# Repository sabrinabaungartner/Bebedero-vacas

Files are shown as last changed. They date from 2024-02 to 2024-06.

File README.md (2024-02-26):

# Bebedero-vacas
El objetivo de este repositorio es almacenar el proyecto, como así también documentos relacionados al proyecto final de carrera Ingeniería en Computación.

## Objetivos
* Asociar dos esp32 con dos LoRa
  * esp32 con un LoRa hacen de transmisores, y el otro LoRa con el esp32 hacen de receptores.
* Sensor de temperatura en el bebedero --> para indicar cuando resulta necesario cambiar el agua.
* Sensor de nivel del agua --> para indicar cuándo se debe rellenar el mismo.
* Sensor de ph --> determina si el agua estancada comienza degradar su calidad.
* Conteo de la cantidad de días sin llenar el bebedero --> determina si el agua estancada comienza degradar su calidad.
* Tomar métricas de cantidad de agua consumida en un día (fecha y consumición).
  * Tipo de vaca: lechera, para carne. Consumirán más o menos líquido. Dependiendo del tipo de vaca, si el ganado es de carne consume 3 litros por día y por cada kilogramo de materia seca consumida, con una temperatura media anual de 5°C. Para un ganado de leche, una vaca lechera consume de 3 a 4 litros de agua por cada kilogramo de leche producida y de 3 a 4 litros de agua por cada kilogramo de materia seca consumida en su dieta.
* App para dueño del campo
  * La app estará tomando valores desde Firebase y decidirá si es necesario enviar una notificación al usuario para informarle sobre algún cambio relevante:
    * Agua en mal estado.
    * Filtrado del agua.
    * Temperatura del agua por arriba o debajo de un cierto umbral.
    * Nivel bajo de agua.
* Hay un LoRa que se va a encontrar en los bebederos. Este dispositivo debe recibir los censados cada cierta cantidad de tiempo y enviárselos al otro LoRa, el cual tomará esos valores y los guardará en la db.

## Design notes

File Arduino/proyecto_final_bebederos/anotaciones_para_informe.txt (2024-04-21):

libreria usada ESP32 Firebase by Rupak Poddar
https://www.arduino.cc/reference/en/libraries/esp32-firebase/
documentacion 
https://github.com/Rupakpoddar/ESP32Firebase/tree/main

// ************************************************** //
ENTRADAS RESERVADAS DEL ESP32 PARA WIFI
Solo se puede usar los puertos del ADC2 cuando el no se usa el wifi. Pines:
* D25
* D26
* D27
* D14
* D12
* D13
* D15
* D2
* D4

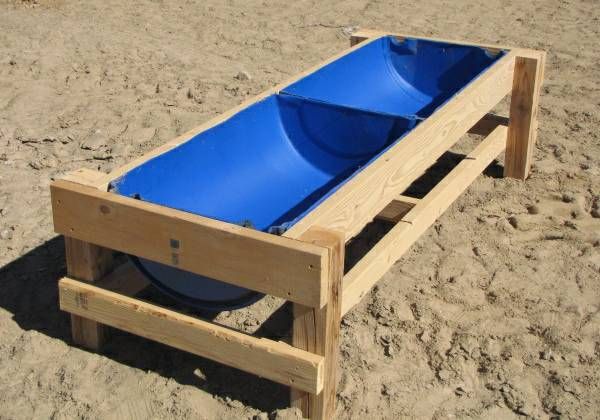
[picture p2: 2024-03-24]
Diseños/Arduino/d69348b3ec312043967b3d7c50ac29f3.jpg

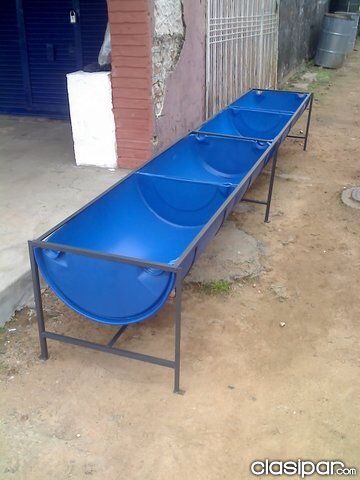
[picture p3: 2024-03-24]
Diseños/Arduino/fdcc297894d32a51d415da545de93732.jpg

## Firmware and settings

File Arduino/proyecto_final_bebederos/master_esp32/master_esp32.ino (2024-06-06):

#include <Arduino.h>
#include "firebase_handler.h"
#include "bt_handler.h"
#include "fnqueue.h"
#include "timer.h"

#define GET_WATER_LEVEL_AND_TEMPERATURE 1
#define REPLY_WATER_LEVEL_AND_TEMPERATURE 2
#define TURN_ON_PUMP 3
#define TURN_OFF_PUMP 4
#define REPLY_TURN_ON_PUMP 5
#define REPLY_TURN_OFF_PUMP 6
#define GET_WATER_LEVEL 7
#define REPLY_WATER_LEVEL 8
#define NULO 0
#define MAX_SECONDS_PUMP_ON 50

// Variables
int seconds = 0;
int seconds_filling_waterer = 0;
int water_level = 0;
int cattle_waterer_selected = 1;
int days_without_fill_waterer = 0;
int filling_waterer = 0;
float water_temperature = 0.0;
bool wifi_is_connected = false;
int max_water_level = 0;
int turn_off_water_pump = 0;
int fill_waterer = 0;
int seconds_pump_on = 0;

// Declaration of functions
void iniciar_timer();
void funcion_timer();
void update_status_cattle_waterer();
void request_and_receive_water_level_and_temperature();
void reset_values_after_filling_waterer();

void request_and_receive_water_level_and_temperature() {
  request_to_slave(GET_WATER_LEVEL_AND_TEMPERATURE);
  receive_from_slave();
  if (get_message_received() == REPLY_WATER_LEVEL_AND_TEMPERATURE) {
    water_level = receive_requested_water_level();
    water_temperature = receive_requested_water_temperature();
    Serial.print("water level value: ");
    Serial.println(water_level);
    Serial.print("water level temperature: ");
    Serial.println(water_temperature);
  }
  else {
    Serial.println("no recibi del slave");
    water_level = 0;
    water_temperature = 0.0;
  }
}

void reset_values_after_filling_waterer() {
  set_fill_waterer(0, cattle_waterer_selected);
  set_last_filling_date(cattle_waterer_selected);
  set_days_without_filling(0, cattle_waterer_selected);
  reset_last_check_filling_date(cattle_waterer_selected);
  set_is_water_pump_enabled(0, cattle_waterer_selected); // Android app detects this change and use it to enable "rellenar bebedero" button
}

void update_status_cattle_waterer() {
  set_current_water_level_value(water_level, cattle_waterer_selected);
  set_current_water_temperature_value(water_temperature, cattle_waterer_selected);
  set_current_date(cattle_waterer_selected);
  update_days_without_filling(cattle_waterer_selected);
}

void funcion_timer() {
  if (!check_slave_is_connected()) {
    Serial.println("Serial BT communicaton is not seted!");
    connect_to_slave();
    seconds = 0;
  }

  else {
    if (seconds == 2) {
      fill_waterer = get_fill_waterer(cattle_waterer_selected);
      if ((fill_waterer == 1) && (filling_waterer == 0)) { // Check if it is necessary to refill the waterer and if it is not filling
          request_to_slave(TURN_ON_PUMP);
          receive_from_slave();
          if (get_message_received() == REPLY_TURN_ON_PUMP) {
            set_is_water_pump_enabled(1, cattle_waterer_selected); // Enable water pump in Firebase
            filling_waterer = 1;
            seconds_pump_on = 0;
            Serial.println("requeri prender la bomba al slave y el slave me respondio que la prendio");
          }
      }
    }

    if (seconds == 4) {
      if ((fill_waterer == 1) && (filling_waterer == 1) && !turn_off_water_pump) { // Check if it is necessary to fill waterer, if it is filling waterer and if not must to turn of the pump
        request_to_slave(GET_WATER_LEVEL);
        receive_from_slave();
        Serial.println("pedi y recibi nivel del agua");
        if ((receive_requested_water_level() >= max_water_level) || (seconds_pump_on >= MAX_SECONDS_PUMP_ON)) {
          turn_off_water_pump = 1;
          Serial.println("la bomab se tiene que apagar!");
          Serial.print("seconds_pump_on: ");
          Serial.println(seconds_pump_on);
        }
      }
    }

    if (seconds == 6) {
      if (fill_waterer == 1) { // Check if it is necessary to fill waterer and if the waterer is filling
        if (filling_waterer == 1) {
          if (turn_off_water_pump) {
            Serial.println("voy a pedir que se apague la bomba");
            request_to_slave(TURN_OFF_PUMP);
            Serial.println("ya mande que se apague la bomba");
            receive_from_slave();
            Serial.println("Pedi que se apague la bomba, voy a ver qye recbo");
            if (get_message_received() == REPLY_TURN_OFF_PUMP) {
              Serial.println("me respondieron que se apago la bomba");
              reset_values_after_filling_waterer();
              filling_waterer = 0;
              turn_off_water_pump = 0;
              fill_waterer = 0;
              seconds_pump_on = 0;
            }
          }
        }
        seconds = 0;
      }
    }

    if (seconds == 8) {
      request_and_receive_water_level_and_temperature();
    }

    if (seconds == 10) {
      update_status_cattle_waterer();
    }

    if (seconds == 12) {
      backup_current_data(cattle_waterer_selected);
      seconds = 0;
    }

    if (filling_waterer == 1) { // Incrementar el contador de tiempo solo si la bomba está encendida
      seconds_pump_on += 1;
    }
  }

  seconds += 1;
}

void iniciar_timer(){
  timer_init(&funcion_timer, 1000000);
  timer_start();
}

void setup() {
  Serial.begin(115200);
  setup_wifi_firebase();
  set_NTP_server();
  setup_bluetooth_configuration();
  fnqueue_init();
  iniciar_timer();
  set_last_filling_date(cattle_waterer_selected);
  reset_last_check_filling_date(cattle_waterer_selected);
  set_days_without_filling(0, cattle_waterer_selected);
  max_water_level = get_max_water_level(cattle_waterer_selected);
  Serial.print("max water level: ");
  Serial.println(max_water_level);
}

void loop() {
  fnqueue_run();
}

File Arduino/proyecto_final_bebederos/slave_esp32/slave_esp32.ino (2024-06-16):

#include <Arduino.h>
#include "slave_serial_bt.h"
#include "water_level_sensor.h"
#include "water_sensor_temperature.h"
#include "fnqueue.h"
#include "timer.h"
#include "water_pump.h"

#define GET_WATER_LEVEL_AND_TEMPERATURE 1
#define REPLY_WATER_LEVEL_AND_TEMPERATURE 2
#define TURN_ON_PUMP 3
#define TURN_OFF_PUMP 4
#define REPLY_TURN_ON_PUMP 5
#define REPLY_TURN_OFF_PUMP 6
#define GET_WATER_LEVEL 7
#define REPLY_WATER_LEVEL 8
#define NULO 0
#define LED_MICRO_ON 22

// Variables
uint8_t seconds = 0;
uint8_t request_received = 0;
uint8_t request = 0;
int water_level = 0;
float water_temperature = 0.0;

void iniciar_timer();
void funcion_timer();
void check_request();
void determine_request();
void response_request();
void read_water_temperatura_from_sensor();
void read_water_level_from_sensor();

void setup() {
  Serial.begin(115200);
  pinMode(LED_MICRO_ON, OUTPUT);
  digitalWrite(LED_MICRO_ON, HIGH);
  setup_bluetooth_configuration();
  setup_water_level_sensor();
  setup_water_temperature_sensor();
  setup_water_pump();
  fnqueue_init();
  iniciar_timer();
}

void loop() {
  fnqueue_run();
}

void iniciar_timer(){
  timer_init(&funcion_timer, 1000000);
  timer_start();
}

void funcion_timer() {
  if (seconds == 1) {
    check_request();
  }

  if (seconds == 2) {
    if (request_received) {
      Serial.println("recibi algo!");
      determine_request();
    }
  }

  if (seconds == 3) {
    if (request_received) {
      response_request();
    }
    seconds = 0;
  }

  seconds += 1;
}

void check_request() {
  request_received = bluetooth_SPP_RxHandler();
}

void determine_request() {
  request = get_message_type_of_request();

  switch(request) {
    case GET_WATER_LEVEL_AND_TEMPERATURE:
      Serial.println("Me pidieron nivel y temperatura");
      read_water_level_from_sensor();
      read_water_temperature_from_sensor();
      break;
    case GET_WATER_LEVEL:
      Serial.println("Me pidieron nivel del agua");
      read_water_level_from_sensor();
      break;
    case TURN_ON_PUMP:
      Serial.println("Me pidieron prender la bomba");
      turn_on_water_pump();
      break;
    case TURN_OFF_PUMP:
      turn_off_water_pump();
      break;
  }
}

void read_water_level_from_sensor() {
  water_level = get_water_level();
}

void read_water_temperature_from_sensor() {
  water_temperature = get_water_temperature();
}

void response_request() {
  switch(request) {
    case GET_WATER_LEVEL_AND_TEMPERATURE:
      Serial.println("Voy a enviar nivel y temperatura");
      bluetooth_SPP_TxHandler(water_level, water_temperature);
      break;
    case GET_WATER_LEVEL:
      bluetooth_SPP_TxHandler(water_level, NULO);
      break;
    case TURN_ON_PUMP:
      bluetooth_SPP_TxHandler(NULO, NULO);
      break;
    case TURN_OFF_PUMP:
      bluetooth_SPP_TxHandler(NULO, NULO);
      break;
  }
}

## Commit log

2024-02-27 Diseño preliminar de la app hecho con Figma
    Link donde se encuentra el diseño: https://www.figma.com/file/cv35BSG2QaFzLYQss9WWen/Untitled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
2024-03-04 se agrego en la interfaz un circulo de barra que muestra un promedio (proximamente) y se empezo a realizar la comunicacion con firebase
2024-03-06 se agrego una manera de que visualmente se vean los cambios realizados desde firebase
2024-03-06 factorizacion y mejora visual de los elementos para mostrar la temperatura promedio, promedio y temperatura maxima
2024-03-08 se acomodo el progressbar para el nivel del agua
2024-03-08 se agrego texto al progress bar del nivel de agua
2024-03-08 se agregaron los tres progressBar de los tres parametros a tener en cuenta
2024-03-10 se agregaron iconos de carga de pantalla principal e icono de app
2024-03-11 se comenzo con el disenio de navigation drawer, para mostrar el historial
2024-03-12 se modifico el disenio de la app para que sea mas amigable visualmente
2024-03-13 se comenzo con la implementacion de las notificaciones push
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2024-03-18 se agregaron seekBars y push notifications usando grupos de notificaciones para hacer la app mas interactiva
2024-03-24 se comenzo con la interaccion de esp32 y firebase
    [conexion-arduino-nrf-esp32.fzz]
2024-03-24 subo un archivo de prueba para ver si la rama main esta todo ok
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2024-03-29 pruebas de bluetooth usando la forma clasica para conexion, ya que es la mas parecida a la conexion usando LoRa
2024-03-30 se agrego en master un led para que prenda cuando slave le envia informacion
2024-03-31 se agrego la opcion de mandar arreglos de bytes para la comunicacion
    [master_bt.ino, slave_bt.ino]
2024-03-31 factorizacion de los archivos de bluetooth del slave
2024-04-04 se hizo la integracion de wifi y bt en el master. Se tuvieron problemas para la integracion, pero ya funciona
    [get_mac_address.ino, master_bt.ino, package.h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]
2024-04-05 se comenzo con modulacion de wifi y bt. Ahora se sube lo relacionado a wifi
2024-04-05 se termino con la integracion y modularizacion de wifi y bt. Ahora se van a crear las funciones y la coordinacion necesaria para implementar lo que resta de las funcionalidades del master
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2024-04-11 se agrega esquema de logica de comunicacion y fnqueue de master
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2024-04-14 se agrego sensor de nivel de agua al slave
2024-04-15 se agrego mandar nivel de agua y fecha a firebase
2024-04-15 se comenzo con el pasaje de los datos en current a los backups
2024-04-17 se comenzo a setear el backup de lso datos en current. Todavia no funciona correctamente el seteo
    [firebase_handler.cpp]
2024-04-19 se termino el pasaje de current data a los backups. se hace arreglo circular del indice actual del backup
    [firebase_handler.cpp]
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2024-04-19 se agrega funcion de crear folders de backup si estos no existen
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2024-04-21 se agregaron consideraciones sobre canal adc y wifi a tener en cuenta
2024-04-21 se agrega sensor de temperatura y se actualizan valores en firebase
2024-04-25 fix problemas con procesamiento en la interrupcion
    [bt_handler.cpp, firebase_handler.cpp, master_esp32.ino]
2024-04-25 se realizaron mas divisiones en las interrupciones y se agrego un todo list para generalizar bebederos
2024-04-26 se agrego opcion de seleccionar bebedero del lado del master
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2024-04-26 se agrega cola de funciones del lado del slave
2024-04-27 se mejora logica de guardado de backups por medio de fechas, y se hace remove de almacenamiento de backups con logica circular
2024-04-29 se agrega funcionalidad de incrementar variable de cantidad de dias sin rellenar el bebedero con la opcion de que ocurra esto si pasan 20 minutos desde el ultimo rellenado
2024-05-01 se agrego login para ingreasar a la app con mail y pw
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2024-05-02 se agrega boton para dar la orden de rellenar bebedero
2024-05-02 se agrega funcionalidad para actualizar fecha de ultimo rellenado en db cuando se presiona boton de rellenar bebedero
2024-05-03 se agrega en master arduino la logica para el control de rellenado. Del lado de android se tienen listeners para obtener el cambio de la variable de rellenado y determinar si se habilita nuevamente e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
2024-05-03 se agrega filtro de backups para tomar promedio de temperatura del agua luego del ultimo rellenado
2024-05-05 update funcionalidad de la toma de niveles del agua desde los bakcups y a partir de la fecha del ultimo rellenado
2024-05-05 modificaciones de notifiaciones push para que se habiliten o deshabiliten segun sea necesario
2024-05-06 fix listener en la funcion que toma los backups filtrados
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2024-05-06 fix funcion getWaterLevels teniendo en cuenta que se lea desde el ultimo rellenado
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2024-05-06 fix push notification de niveles del agua para que notifique una sola vez al usuario cuando se deba cambiar el agua
2024-05-06 Fix mostrar mensaje de error si no se puede hacer get de la calidad del agua en funcion que muestra la calidad del agua en la app
2024-05-07 fix en la toma de fecha para setear las rutas de los backups
    [firebase_handler.cpp, master_esp32.ino]
2024-05-07 fix toma de valores del nivel del agua. se parte el valor int en 4 bytes, se envian al master y este ultimo convierte los 4 bytes nuevamente a un int
    [bt_handler.cpp, master_esp32.ino, package.h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]
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2024-05-11 fix funcion de actualizar dias sin rellenar cada 20 minutos si no hubo un rellenado
    [bt_handler.cpp, firebase_handler.cpp, master_esp32.ino]
2024-05-11 fix prints en clase firebase y se saca check de wifi (se reconecta solo gracias a una funcion seteada a comienzo
    [firebase_handler.cpp, master_esp32.ino]
2024-05-13 fix en la funcion principal para tomar muestras y luego guardarlas
    [bt_handler.cpp, firebase_handler.cpp, master_esp32.ino]
2024-05-13 se agrega un nuevo filtrado para tomar unicamente los ultimos 10 backups mas recientes y hacer el promedio
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2024-05-19 se sacaron progressBar de nivel de agua y calidad del agua, y se cambiaron por imagenes. Tambien se acomodaron otras cuestioens esteticas
2024-05-20 se agrega programa para probar la bomba a acoplar al proyecto final
2024-05-21 fix de toma de niveles del agua, ya que el sensado no estaba haciendose de manera correcta
    [slave_esp32.ino, slave_serial_bt.cpp]
2024-05-21 se agrega logica en pseudocodigo para el llenado del bebedero con la bomba
2024-05-23 fix funcion timer para evitar errores al hacer get o set de firebase, debido a que se necesita mas tiempo entre cada funcion para ser llamadas. Cada tanto alguna funcion falla, pero la tasa mejoro no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
    [master_esp32.ino]
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2024-05-30 se agrega timer para apagar bomba cuando se cumpla determinado tiempo, ademas de chequear nivel maximo del agua
2024-06-01 fix graficos para que muestre las fechas en las puntas
2024-06-02 fix sensor agua en pruebas varias y update de cantidad de segundos antes de apagar la bomba como alternativa a usar el nivel de agua como referencia
    [master_esp32.ino, sensor_agua.ino]
2024-06-02 Fix caracteristicas de la app y borrado de funciones o comentarios sin uso
2024-06-02 fix porcentaje maximo de temperatura
2024-06-03 se comenta funcionalidad graficos para probar eficiencia del resto de la app de forma individual
2024-06-03 se agrega datos de backup de firebase en carpetas para mejorar filtrado de datos
2024-06-03 fix graficos al cambiar estructura de la base de datos
2024-06-06 cambio en la manera de guardar backups y delete de variables en firebase que no se usaban. se hizo update de esas variables para que se manejen de forma local en el master de arduino
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2024-06-16 se agregaron leds en la caja que contiene la conexion de sensores y bomba al slave y se agrego en master para subir la fecha del ultimo rellenado a firebase
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
